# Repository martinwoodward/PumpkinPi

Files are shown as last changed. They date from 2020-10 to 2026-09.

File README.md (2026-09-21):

# PumpkinPi
Spooky build status indicator.

## Plasma 2350 W version

The new [Plasma 2350 W models](stl/plasma-2350-w/) include a board holder, a
pumpkin body with a smoothed Octocat and a USB-C panel-mount fit coupon,
with before/after previews.
See the [Plasma runtime guide](docs/plasma-runtime.md) for the offline-tested
96-LED MicroPython firmware and standalone GitHub HTTPS with a board-local token.
See the [implementation plan](docs/plasma-copilot-plan.md) for its accounting and safety
contract. Live billing and physical hardware gates remain intentionally unclaimed;
the Raspberry Pi setup below remains the unchanged legacy application.

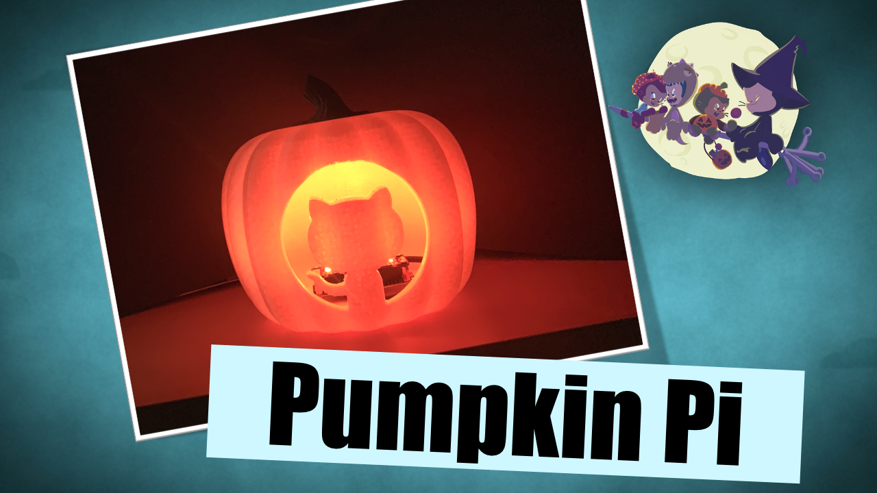
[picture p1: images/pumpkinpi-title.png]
Pumpkin Pi


## Hardware Requirements:
This project makes use of the following:
 - Pumpkin - Carve a real one or you can always [3D print one](#3d-printed-pumpkin)
 - Raspberry Pi Zero WH  ([UK](https://amzn.to/33rmXEc), [US](https://amzn.to/3lcQLul))
 - Pimoroni Unicorn pHat  ([UK](https://amzn.to/3l8rPnR), [US](https://amzn.to/30wEWaG)). Note discountinued now so you might want to try the [Unicorn HAT Mini instead](https://shop.pimoroni.com/products/unicorn-hat-mini)
 - Micro SD Card  ([UK](https://amzn.to/2SoRagP), [US](https://amzn.to/2GeMWWT))
 - USB power - I used the official Raspberry Pi Charger ([UK](https://amzn.to/33qvreN), [US](https://amzn.to/36yKkh4)) but you can also power with a USB battery pack.

 ### 3d Printed Pumpkin
 For the [3d printed pumpkin case](stl/), you will need:
  - Glow in the Dark PLA Filament for body  ([UK](https://amzn.to/2SmQzwj), [US]())
  - Green PLA Filament for top  ([UK](https://amzn.to/2GeMlo7), [US](https://amzn.to/30vuAHX))
  - Adafruit Panel Mount Extension USB Cable - Micro B Male to Micro B Female [ADA3258] ([UK](https://amzn.to/3irYgf9), [US](https://amzn.to/34pR51V))
  - 4 x M2.5 threaded brass inserts ([UK](https://amzn.to/3ixudCK), [US](https://amzn.to/33rnYw0))
  - 4 x M2.5 male PCB standoffs & screws - keep a kit of these handy if you don't have some. ([UK](https://amzn.to/3cYGkYE), [US](https://amzn.to/3l8VDk8))

When ordering online, while Amazon ([US](https://amzn.to/2CUGild)) and Amazon ([UK](https://amzn.to/2PbHDtz)) are always handy places (especially if you are a Prime member) I also highly recommend [AdaFruit](https://www.adafruit.com/) for electronics purchases in the US and [PiHut](https://thepihut.com/) in the UK. They basically should just park a truck at my house and take all my money.

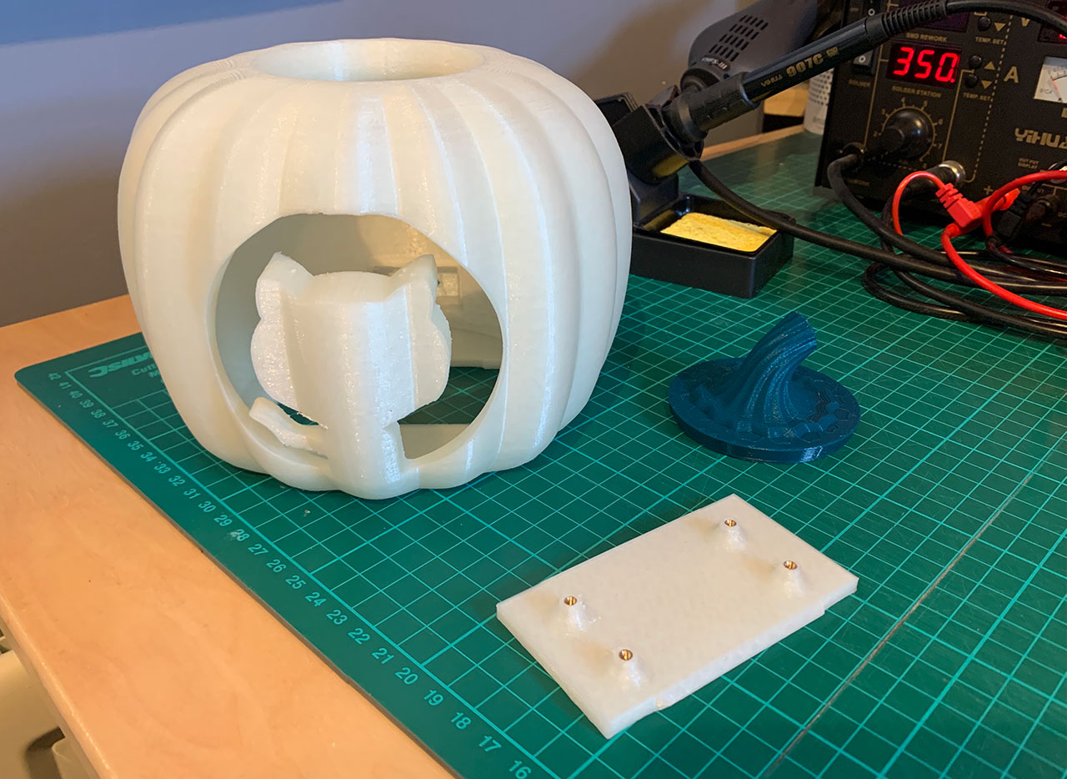
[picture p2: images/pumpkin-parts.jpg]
Pumpkin Pi


## Getting Started

Format the micro SD Card and [install Raspberry Pi OS Lite](https://www.raspberrypi.org/downloads/raspberry-pi-os/). If installing onto a Pi Zero you might not have the keyboard and HDMI adapters lying around so you probably want to do a [headless install](https://www.raspberrypi.org/documentation/configuration/wireless/headless.md), configuring SSH and WiFi by dropping an `ssh` file and a `wpa_supplicant.conf` file onto the root of the SD card after copying over the Raspbian files.

You'll need to install the [Unicorn HAT](https://github.com/pimoroni/unicorn-hat) software but they have a cool one-line installer that takes care of all the dependencies including Python and Git.

``\curl -sS https://get.pimoroni.com/unicornhat | bash``

In addition, we'll be using the ``requests`` module in python so after installing the Unicorn HAT software, install the ``requests`` module with the following command

``sudo pip install requests``

Next you want to clone this git repo. I have it at the root of the standard ``pi`` user

``git clone https://github.com/martinwoodward/PumpkinPi.git``

You need to modify the settings to point at your build badge. First of all copy the sample settings provided in the repo:

``cp ~/PumpkinPi/src/local_settings.sample ~/PumpkinPi/src/local_settings.py``

Then edit the ``BADGE_LINK`` variable and point at the URL of your Build badge.

```python
# Build Badge for the build you want to monitor
BADGE_LINK = "https://github.com/martinwoodward/calculator/workflows/CI/badge.svg?branch=main"
# How often to check (in seconds). Remember - be nice to the server. Once every 5 minutes is plenty.
REFRESH_INTERVAL = 300
```

Finally you can run the script as root

```
sudo python ~/PumpkinPi/src/pumpkinpi.py &
```

Once you are happy everything is running how you want, don't forget you can run the script at boot time. The easiest way to do this is to use crontab. See this [cool video from Estefannie over on the Raspberry Pi blog](https://www.raspberrypi.org/blog/how-to-run-a-script-at-start-up-on-a-raspberry-pi-using-crontab/) to learn more.  But basically do ``sudo crontab -e`` then add the following:

```
@reboot /bin/sleep 10 ; /usr/bin/python /home/pi/PumpkinPi/src/pumpkinpi.py &

```

Note that we are pausing for 10 seconds before running the python script. This is to allow the network to come up. We could make the python script more resilient to network outages and/or start up the script using [systemd](https://www.raspberrypi.org/documentation/linux/usage/systemd.md).

Pumpkin Pi

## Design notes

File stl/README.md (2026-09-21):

## 3D model files for Pumpkin Pi

For the **Plasma 2350 W**, see the [new model variants](plasma-2350-w/):
a replacement holder, a body with a smoothed Octocat, USB-C panel-mount revisions and preview
images. The original Pi Zero files below are retained unchanged.

There are 3 main components for the Pumpkin Pi.
 - [pumpkin-body.stl](pumpkin-body.stl) - the main body of the pumpkin. I printed without supports using glow in the dark PLA filament. Infil 15% gyroid pattern.
 - [pumpkin-pi-holder.stl](pumpkin-pi-holder.stl) - an insert that snap fits into the bottom of the pumpkin. I printed mine in the same run as the body with same settings.
 - [pumpkin-plug.stl](pumpkin-plug.stl) - the stalk part of the pumpkin that slots into the top. I printed mine in dark green PLA filament.

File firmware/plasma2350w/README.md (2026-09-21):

# Plasma 2350 W firmware

This MicroPython application drives a 96-pixel AI-credit candle using
**standalone GitHub HTTPS**. It
stores Wi-Fi credentials and the GitHub token on the Plasma 2350 W itself; no
computer or Copilot process needs to remain running.

## Standalone setup

1. Install the Pimoroni **Plasma 2350 W v1.1.0** UF2.
2. Create local private files from the committed templates:

   ```bash
   cp firmware/plasma2350w/config.github.example.json firmware/plasma2350w/config.json
   cp firmware/plasma2350w/.env.example firmware/plasma2350w/.env
   chmod 600 firmware/plasma2350w/.env firmware/plasma2350w/config.json
   ```

3. Edit `.env` **locally, not in chat or a shell argument**. Set `WIFI_SSID`,
   `WIFI_PASSWORD`, and `GITHUB_TOKEN`. This is a literal file, not a shell script:
   optional matching quotes are removed, but escapes, interpolation, `export`,
   and inline comments are not supported. A password can contain `#` or `=`.
   Blank values, duplicate/unknown keys and control characters are rejected.
4. Edit `config.json`: supply the actual payer/account, an approved
   `allowance_microcredits` (one credit = 1,000,000 microcredits), and verified
   `unit_type`, `product`, `sku`, and `quantity_field` from that account's billing
   response. For an organization or enterprise set `owner_type`, `owner` and,
   if appropriate, `source.subject`. See [accounting requirements](../../docs/plasma-runtime.md#live-source-provisioning).
   Empty template fields intentionally prevent live startup and select a
   clearly marked setup demo; there is no guessed quota or demo data in live mode.
5. The template selects `exhaustion_policy: "configured-budget"`: zero triggers
   the exhausted animation for **your named monthly budget**, not necessarily
   your GitHub account. Use `"none"`
   for an estimated allowance that must not claim exhaustion. Change
   `budget_revision` when you change the budget.
6. Reboot normally into MicroPython, connect the serial USB port, then upload:

   ```bash
   python3 -m venv .venv
   .venv/bin/python -m pip install -r firmware/plasma2350w/requirements.txt
   .venv/bin/python firmware/plasma2350w/deploy.py install \
     --device /dev/cu.usbmodemXXXX \
     --mpremote .venv/bin/mpremote \
     --config firmware/plasma2350w/config.json \
     --env firmware/plasma2350w/.env
   .venv/bin/mpremote connect /dev/cu.usbmodemXXXX reset
   ```

The actual `.env` and `config.json` are ignored by Git; `.env.example` is tracked.
Only explicit `--env` uploads secrets, to the board's `/.env`. The token never
appears in command arguments, normalized snapshots, status or network errors.
Board flash is **not encrypted secret storage**: anyone with physical access can
read it. Use a minimally privileged, revocable token. To rotate it, update the
private `.env`, upload that file with `mpremote ... fs cp path/to/.env :.env`,
reset the board and revoke the old credential. Do not commit flash dumps or
private backup files.

### Network, time and trust

The board cooperatively performs DHCP-resolver IPv4 DNS, NTP bootstrap, and
GitHub HTTPS. The actual RTC is set before TLS starts (including 2000-epoch
MicroPython ports). NTP is **unauthenticated clock bootstrap**, not server
authentication. Every request requires a trusted CA and the hostname
`api.github.com`; no redirect is followed and no `CERT_NONE` fallback exists.
See [the bundled CA's provenance and rotation](certs/README.md).

GitHub's verified HTTP Date must agree within five minutes. A saved
`direct-time.json` lower bound rejects substantial rollback across boots; it is
updated at most once daily after a verified response. A corrupt or unreadable
file is an explicit startup error: inspect the device rather than silently
discarding rollback protection. Time resynchronizes every six hours and after
TLS/time disagreement; the filesystem and RTC must be functional.

Allow outbound DNS (UDP 53), NTP (UDP 123), and HTTPS (TCP 443). `ntp_host` can
name a local NTP server if public NTP is blocked. DNS and NTP have five-second
deadlines; a full HTTPS operation has fifteen seconds, 8 KiB of headers and a
32 KiB body maximum. Billing normalization is limited to 512 rows with exact
decimal arithmetic, not float-rounded credit quantities. Oversized or unsupported
responses fail visibly rather than truncating usage or displaying a guessed balance.

Polling defaults to five minutes and honors rate-limit delays with bounded-work
exponential retries. GitHub's reporting latency is unknown, so effects represent
**newly reported** consumption, not every keystroke. DNS/TLS/HTTP progress is
cooperative with the 30 fps scheduler; no `urequests.get()` blocks the render loop.
Failures preserve the prior observation without renewing freshness or inventing
zero. The onboard status LED signals errors/staleness. A serial REPL traceback
identifies startup configuration errors. Actual UF2 frame timing still needs
measurement; cryptographic work and JSON parsing are not preemptible.

## Candle behaviour and button A demo

Full credits show a **golden flickering candle with recurring white sparkles**.
The palette passes through orange/red and purple as the balance falls; sparkles
stop below 100%. At confirmed zero the two-second sputter now settles into a
**dull purple flicker**, not complete darkness. Repeated zero reports do not
restart it. When credits return, the light rises to bright white over **one
second**, then blends into the credit-dependent candle over half a second.
At full balance this is golden with white sparkles again. An unconfirmed
estimated zero keeps the existing brighter low-balance purple instead.

An unlimited basis must be explicitly approved: set `source.unlimited: true` and
`source.allowance_microcredits: null` in the board config. Unlimited
snapshots still require a successful, mapped usage report; missing data, null
allowance alone, paid overages and authentication errors never imply unlimited
credits. Sparkles continue while the configured unlimited basis is active.

Press **A** (active-low `SW_A` / GPIO12 on the Plasma 2350 W, with a pull-up and
50 ms debounce) to enter animation demo mode. The sequence is:

| Stage | Duration |
| --- | --- |
| Three white flashes | 250 ms on, 250 ms off each (1.5 s total) |
| Dark pause | 15 s |
| Full golden candle with white sparkles | 10 s |
| Smooth simulated consumption from 100% to zero | 30 s |
| Exhausted state | 5 s, including the initial 2 s sputter then dull flicker |
| Recharge to white | 1 s, then 0.5 s blend into golden |
| Repeat the complete sequence, including flashes and pause | Three cycles total (63 s each) |
| Full orange/golden flickering candle with recurring white sparkles | 60 minutes |
| Replay the complete sequence once, then return to the 60-minute candle | Repeats until reset/power-off |

The initial three cycles take 189 seconds. The first hourly replay begins at
3,789 seconds after demo entry and finishes at 3,852 seconds. Each subsequent
hold lasts a full 3,600 seconds, followed by one 63-second sequence. Timing uses
monotonic elapsed time, not wall-clock synchronization or frame count; delayed
frames do not accumulate timing drift. Each new cycle clears prior animation
effects without resetting or populating live accounting.

Demo is latched in memory: more button presses and later network availability do
not restart or cancel it. Polling stops and active sockets close; synthetic demo
values never enter live accounting or persistent billing state. The onboard
status LED is **blue** and the serial console gives a secret-free entry reason.

Every fully provisioned boot starts in **normal mode**. If no fresh, valid balance arrives within
**30 seconds**, it enters the same demo automatically. Set
`startup_demo_timeout_seconds` (greater than 0, at most 300) to allow a slower
network. Wi-Fi, DNS, TLS, authorization or unsupported-response failures can all
prevent a usable startup reading; the recorded error remains available for
diagnostics. A later outage after a successful startup stays in normal mode with
the existing stale/error indication, rather than switching to synthetic full
credits. Reset/power-cycle to retry live mode after fallback.

Missing, unreadable or invalid `config.json` / `.env` instead reports a
secret-free **Setup required** error and immediately enters the same latched
demo with blue status. No network provider is created and live accounting stays
unknown. The error remains in the reducer for diagnostics. An invalid config
uses the default RGB order, 96 pixels, 100% requested brightness and modeled 1.5 A cap; an invalid
environment with a valid config preserves that config's electrical settings.
Hardware/code failures and corrupt TLS time-floor state still fail explicitly,
not as setup demos. Complete the settings and reset to retry live mode.
All frames, including flashes,
recharge white and sparkles, obey the same brightness/current caps; "bright"
never means bypassing the configured electrical limit.

## Deployment details

The RP2350 BOOTSEL drive is a UF2 bootloader volume, **not** the MicroPython user
filesystem: do not copy `.py` files to it. The `install` command uses `mpremote`
to create package directories and upload `main.py`, the scheduler, hardware
adapter, GitHub provider, cooperative networking, the CA certificate, every
`pumpkinpi_core/` module, and only explicitly supplied private files.

For inspection or packaging without a device:

```bash
python3 firmware/plasma2350w/deploy.py bundle build/plasma-firmware
```

The bundle command accesses only the named local folder and never uploads secrets.
The deployment requirement is only `mpremote`; no desktop runtime is installed.

### Windows serial REPL and first deployment

The attached board was identified on **COM5** as `plasma_2350_w`, MicroPython
1.27.0 (2026-03-02), `Pimoroni Plasma 2350 (LTE + WiFi) with RP2350`.
Discover the current port rather than assuming COM5 on another machine:

```powershell
Get-CimInstance Win32_SerialPort | Select-Object DeviceID,Name,PNPDeviceID
python -m venv .venv
.\.venv\Scripts\python.exe -m pip install -r firmware\plasma2350w\requirements.txt
.\.venv\Scripts\mpremote.exe connect COM5 exec "import os, sys; print(os.uname()); print(sys.implementation); print(os.listdir())"
```

`mpremote` uses MicroPython's raw serial REPL. `exec`, `run` and `fs` normally
interrupt the application and soft-reset the interpreter; they are not passive
monitoring. Use one serial client at a time, close editors/serial monitors first,
and always reset after inspection to leave `main.py` running autonomously.
Preserve an existing boot program on the board before the first overwrite; do
not read or dump existing credentials. This board's prior boot program is
preserved as `main-before-pumpkinpi.py` (the pre-existing `main-original.py` and
`secrets.py` were left untouched).

For an **explicitly approved unprovisioned setup**, upload the blank templates:

```powershell
.\.venv\Scripts\python.exe firmware\plasma2350w\deploy.py install --device COM5 --mpremote .\.venv\Scripts\mpremote.exe --config firmware\plasma2350w\config.github.example.json --env firmware\plasma2350w\.env.example
.\.venv\Scripts\mpremote.exe connect COM5 run firmware\plasma2350w\verify_demo.py
.\.venv\Scripts\mpremote.exe connect COM5 reset
```

The board gets `/config.json` with empty account/mapping fields and a `_setup`
array of instructions (JSON does not allow comments), plus `/.env` with comments
and blank credentials. **Do not overwrite provisioned private files with these
templates.** For code-only updates omit both `--config` and `--env`. To provision
live mode later, edit ignored local copies and explicitly upload those files;
do not paste secrets into REPL commands or chat.

`verify_demo.py` executes from the host through the REPL without installing a
test program on the board. It exercises real hardware for roughly 191 seconds
(plus up to the configured startup timeout), checks all three initial cycles
and the orange hold, nonzero
output in each lit phase, the dark pause, power/brightness limits, and absence
of synthetic billing snapshots. It is for an unprovisioned/offline board, not
one currently showing a valid live balance. It blacks the strip on exit, so
**reset afterward**. Its checks add rendering overhead; do not interpret its
frame count as an uninstrumented frame-rate benchmark. It then advances the
demo timestamps through two hourly replays to check exact 60-minute boundaries
and real hardware writes without waiting two hours; this is not a real-time
two-hour soak. Serial verification
cannot establish perceived colors, measured electrical current or temperature.
On the attached board a separate, uninstrumented golden-candle sample rendered
128 frames in 10.06 seconds (about 12.7 fps), below the 30 fps scheduler target.

Start with 96 WS2812 pixels in **RGB order**, matching this board's `fire.py`
and `rainbows.py` examples. GRB swapped red/green and made the golden candle
look green on the attached strip. Set `color_order` explicitly for other strips;
do not compensate by changing the logical candle palette. The strip is black before
`strip.start(60)`. The default requests 100% brightness, matching the existing
board examples (`rainbows.py` uses HSV value 1.0; `fire.py` reaches toward 1.0;
`sparkles.py` reaches RGB values near 254). Those examples address 50 pixels,
not this application's 96, and do not establish safe full-strip white current.
The provisional **1.5 A total modeled-current cap remains active**, scaling
bright frames down as needed. Existing explicit brightness settings are
preserved on code-only updates; edit `max_brightness` to `1.0` to opt in.
These brightness and current settings are not
electrical certification; identify the LEDs and verify current with a meter.
Fatal errors and normal interpreter shutdown execute a final blackout, but physical
power-loss behavior must still be checked on the actual DMA/strip firmware.
The onboard status LED uses Pimoroni's documented
`RGBLED("LED_R", "LED_G", "LED_B")` pin-name API.

## Hardware gates

Board entropy, DNS/NTP/HTTPS timing, onboard RGB LED pin names,
actual colour order, current, temperature, and an eight-hour soak remain physical
tests. The HTTPS implementation has host tests including real local TLS success,
wrong CA/hostname and expired-certificate rejection without transmitting an
application credential. Public DNS, NTP and GitHub TLS with the bundled root
were also exercised from the host, using a synthetic invalid credential (401).
The serial deployment and full setup-demo sequence have now been exercised on
the attached physical board with blank credentials. No actual billing token was
supplied: live entitlement/unit mapping, RP2350 networking/heap behavior under
load, physical color/current/temperature checks and soak testing remain gates,
not claims inferred from the setup demo.

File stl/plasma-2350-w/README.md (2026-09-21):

# Plasma 2350 W PumpkinPi models

These are new variants; the original Pi Zero STLs remain unchanged in the parent
directory. All dimensions are **millimetres**. New files are **Z-up, base on Z=0**,
ready for normal upright printing. Do not auto-rotate them onto their sides.

| File | Purpose |
| --- | --- |
| [plasma2350-holder.stl](plasma2350-holder.stl) | Plasma 2350 W insert, retaining the original snap-fit perimeter |
| [pumpkin-body.stl](pumpkin-body.stl) | Original shell with an evenly thinned Octocat and revised USB-C panel opening |
| [usb-c-fit-coupon.stl](usb-c-fit-coupon.stl) | Small, flat-printed connector-pattern trial; print this first |
| [measurements.json](measurements.json) | Regenerated mesh measurements and geometry checks |

Use the existing [pumpkin-plug.stl](../pumpkin-plug.stl) for the stalk. It is still
in the legacy Y-up orientation: rotate it -90 degrees about X and place its bottom
on the bed when printing separately.

## Holder

The board is **Plasma 2350 W**, not a Pi Zero or the non-wireless Plasma 2040.
Pimoroni specifies a 60 x 22 mm PCB and an approximately 61 x 22 x 12 mm assembled
envelope including connectors. The new insert has two diagonal mounting bosses,
not the Pi Zero's four.

The [W-specific pinout drawing][pinout-w] and the [originally supplied pinout][pinout]
show two M2 mounting holes. The inferred centre separation is **55.6 x 17.6 mm**:
the vector drawing places their centres 2.2 mm in from each PCB edge. This pitch is
measured from the scaled drawing, not explicitly dimensioned by its author.
Check it against the physical board before tightening screws.

- Boss tops are at Z=11: **6 mm clearance above the plate** for underside components.
- Two **2.4 mm through-bores**, with **4.3 mm across-flats, 2 mm deep M2 nut pockets**
  entered from below. The pockets taper into the bores to avoid horizontal roofs.
- Use two M2 nuts and approximately **M2 x 12 mm screws**, adjusting length for
  actual PCB thickness and washers. Use insulating washers and do not overtighten.
  Do not substitute the old M2.5 inserts.
- Retained plate envelope: **89 x 54 mm**, with the original 5 mm thick snap profile.
  Screws/nut pockets only alter its interior, not the mating rim.
- Both board ends are open for the USB-C plug and LED terminal wiring. The preview
  ghost is a PCB envelope, not a component-accurate clearance model.
- Install the board and cable on the holder before snapping it into the pumpkin;
  keep the 30 cm cable loosely routed around the interior, away from LED wiring
  and the wireless module. Check the actual 37 mm plug/strain-relief envelope and
  cable bend radius during dry assembly.

## Body and support constraints

The body retains the original shell and crown, with a locally smoothed Octocat
and the USB-C revision described below.
The first 6 mm of the body and the stalk seat from Z=112 upward are unchanged.

### Smooth Octocat back

The Octocat has a **3.2 mm front-to-back wall** instead
of letting the general cavity leave ridges and a thick wedge behind its head.
The back follows a smooth offset of the existing sculpted front, preserving the
visible silhouette and outer surface. The lower front wall continues the relief
into the original base, without a new unsupported ledge. The surrounding crown
still retains its support-free roof; only the logo is uniformly thinned.

This dimension is measured along Y (front to back), not perpendicular to every
facet of the curved exterior. The generator checks 2,266 points across the head,
stem and tail; the exported surfaces measure **3.17-3.26 mm**, excluding rays
grazing the original cutout bevels. It also checks the front surface is unchanged
and introduces no new steep underside faces. The smooth offset is reconstructed
from the source exterior, not from the jagged old inner wall.

### Printing

The generator checks the actual exported meshes are single watertight solids,
checks both old/new holders against the body, and rejects newly introduced downward
faces above 45 degrees **except the flat USB ceiling**. This is an explicitly
accepted **11.6 mm bridge for the Bambu X1C**; the exception is constrained to that
ceiling, not the rest of the shell. The source pumpkin already contains steep
faces/bridges, so not every pre-existing face is below that angle. Inspect the sliced
layers, particularly the face and rear connector, with bridging enabled.

Starting point: PLA, 0.4 mm nozzle, 0.2 mm layers, 3-4 perimeters, 10-15% infill,
supports off, brim only if needed for bed adhesion. Use the same settings when
comparing slicer filament estimates. Glow PLA is abrasive; use a
suitable nozzle. No physical test print or thermal test has been performed.

## USB-C panel mount: provisional fit, coupon first

The supplied [BTFO USB-C panel extension][cable] drawing gives:
30 cm cable, 25 x 10 mm flange, approximately 35 mm female housing length,
37 mm male housing length and 9 mm screws. **It does not specify screw-centre
spacing, screw diameter, through-panel cutout or rear housing cross-section.**
Do not infer a guaranteed fit from the illustration.

The old micro-B opening was 10 x 5 mm with bores on a 16.5 mm pitch. The Plasma body
uses:

- An **11.6 x 6.8 mm rectangular opening** with a flat, bridged ceiling.
- Nominal **19 mm screw pitch** with 4.8 mm diagonal diamond bores. Their inscribed
  circular diameter is about 3.39 mm; these are clearance holes, not printed threads.
- The same recessed rear position and 2 mm mounting face.
- No triangular vent above the opening. The 6.8 mm height fits within the pictured
  centred 10 mm-high flange, without the previous 4.2 mm protruding tip. This is
  still not a sealed or weatherproof connector mount.

Print `usb-c-fit-coupon.stl` (34 x 19 x 2 mm) first, use the supplied cable to verify
the aperture and screws, and measure the flange and inner moulding against the
recess. **The coupon checks the face pattern, not rear housing or cable clearance.**
Check the supplied 9 mm screw engagement in the actual connector; add washers or
use shorter screws if they bottom out. Never force the plastic or connector.

If needed, update `MOUNT_X` (half the screw pitch), `PORT_WIDTH`, and `PORT_HEIGHT`
in the generator, then regenerate **both the coupon and body**. Verify that
there is still material between holes and that the flange covers the intended
opening. A measured connector cutout drawing is required to finalize this fit.

## Rebuild and previews

From the repository root:

```sh
python3 -m venv .venv
.venv/bin/python -m pip install -r stl/tools/requirements.txt
.venv/bin/python stl/tools/build_plasma.py
```

The generator uses the original binary STLs as source, not an approximate
replacement pumpkin. It preserves their licence and produces new binary STLs,
measurement JSON and the previews below. No CAD application is required.

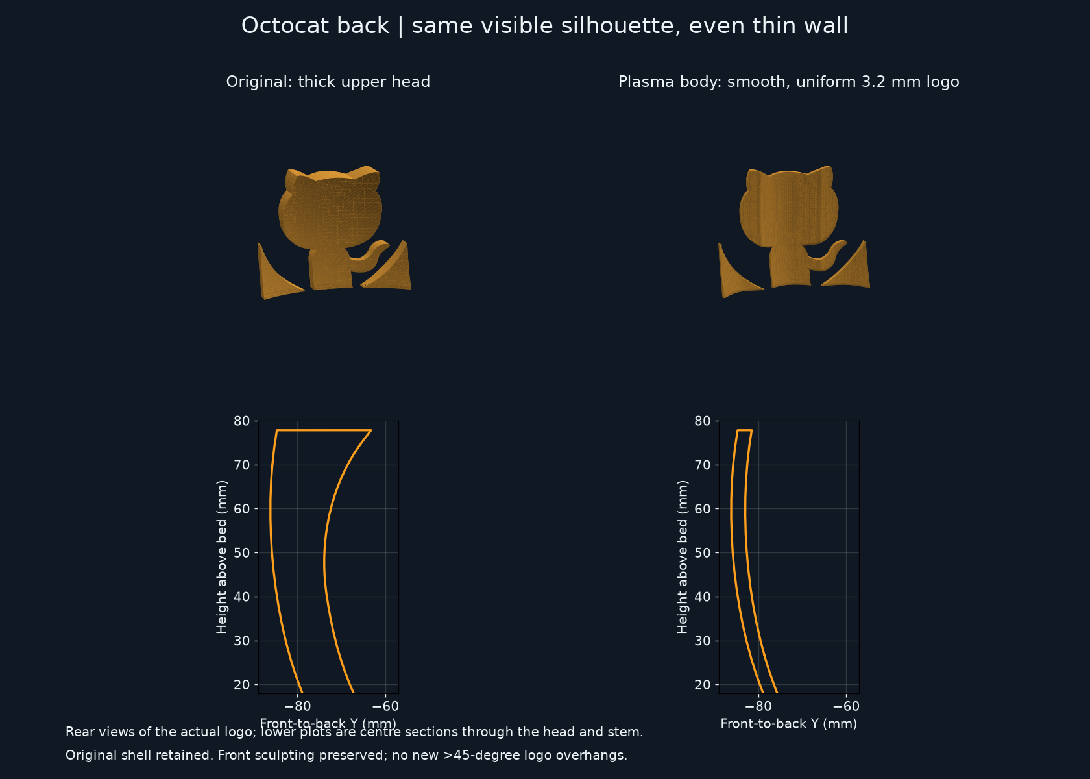
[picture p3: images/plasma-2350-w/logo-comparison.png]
Octocat back before and after, with wall-depth sections


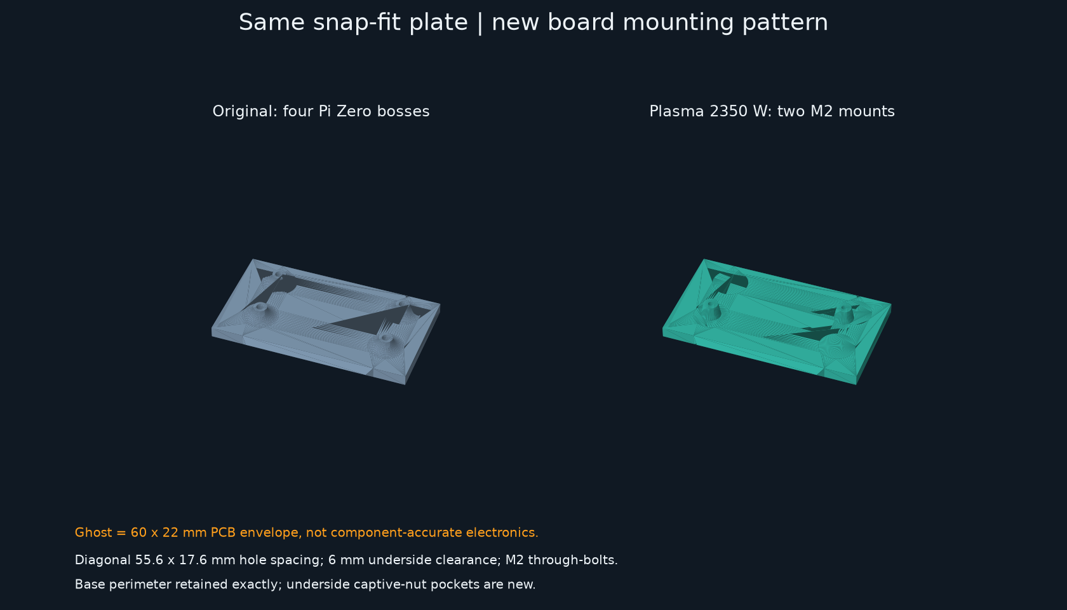
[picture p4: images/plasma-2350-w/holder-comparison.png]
Original and Plasma mounting plates


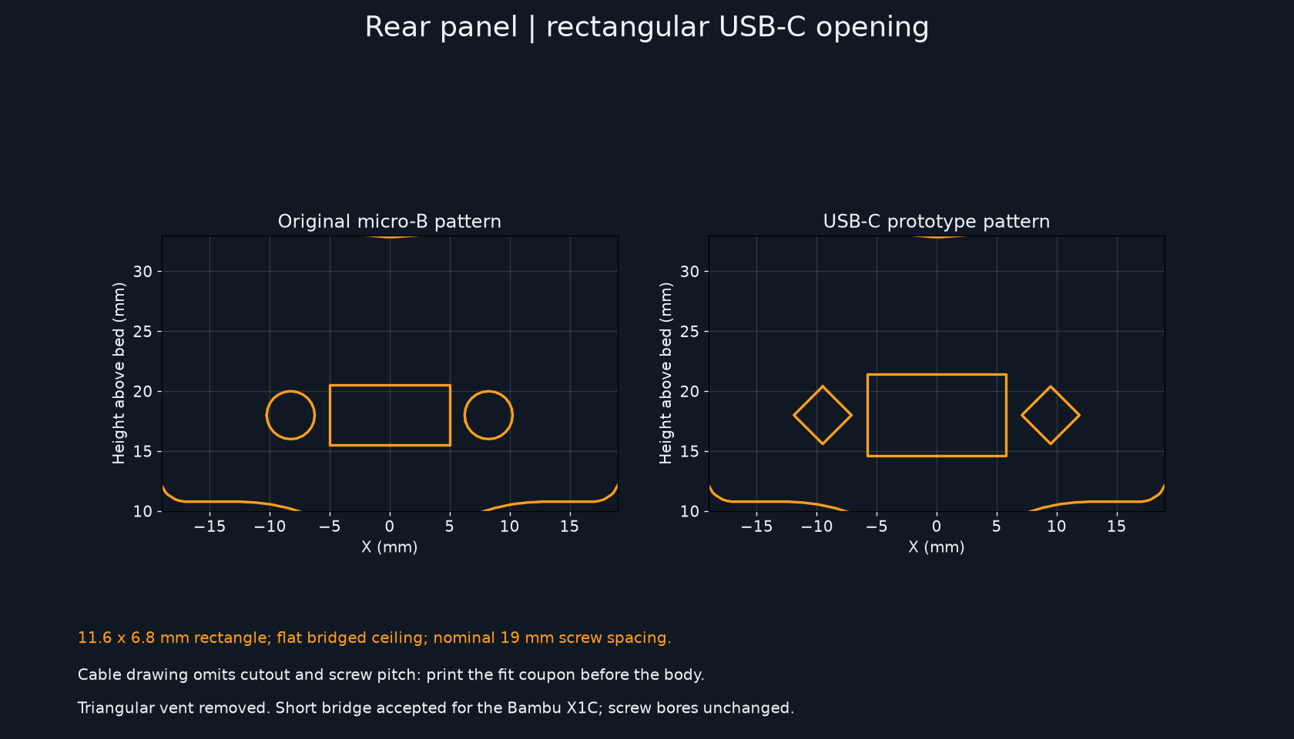
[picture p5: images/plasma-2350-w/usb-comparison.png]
Original and USB-C panel patterns


See the [preview gallery](../../images/plasma-2350-w/index.html) and
[Copilot credit-lamp implementation plan](../../docs/plasma-copilot-plan.md).

[pinout]: https://cdn.shopify.com/s/files/1/0174/1800/files/plasma2350_pinout_diagram.pdf?v=1723124465
[pinout-w]: https://cdn.shopify.com/s/files/1/0174/1800/files/plasma2350_w_pinout_diagram.pdf
[cable]: https://www.amazon.co.uk/dp/B0H7S5WSC5

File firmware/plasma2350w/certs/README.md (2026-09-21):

# GitHub HTTPS trust anchor

`github-root.pem` contains the public **USERTrust ECC Certification Authority**
root, extracted from the development host's trusted CA store on 18 September
2026. It contains no private key or account credential.

- DER SHA-256: `4ff460d54b9c86dabfbcfc5712e0400d2bed3fbc4d4fbdaa86e06adcd2a9ad7a`
- Expiry: 18 January 2038.
- Observed `api.github.com` chain: `*.github.com` ->
  `Sectigo Public Server Authentication CA DV E36` ->
  `Sectigo Public Server Authentication Root E46` ->
  `USERTrust ECC Certification Authority`.

The shipped cooperative HTTPS transport validated GitHub's current chain using
this bundle during a credential-free connectivity check (a synthetic invalid
bearer value received the expected HTTP 401). Local TLS tests also reject
untrusted roots, hostname mismatch and expired certificates before application
headers are transmitted.

This is a deliberately small **root trust bundle**, not a pinned GitHub leaf
certificate or a promise that GitHub will retain this issuer. Normal leaf
renewals under the same chain need no update. If GitHub changes its chain,
obtain the required root from a trusted CA distribution, independently verify
its subject/fingerprint and validity, update this file and its fingerprint test,
and redeploy it. A MicroPython `cafile` can contain multiple PEM roots if needed
for a verified transition. Do not trust a certificate solely because a failed
connection presented it, pin a short-lived leaf to work around missing roots,
or disable `CERT_REQUIRED`/hostname checks.

The actual board RTC must be set before certificate validity checks. NTP is
unauthenticated bootstrap; the firmware additionally compares verified HTTP Date
and persists a daily lower time bound. Physical access can modify both flash and
the stored credential, so this does not provide tamper-resistant storage.

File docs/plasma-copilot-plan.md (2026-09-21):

# Plasma PumpkinPi: standalone credit candle design

Target: **Plasma 2350 W, 96 RGB LEDs**. The existing Raspberry Pi application in
`src/` remains separate and unchanged. The firmware implementation and desktop
tests are complete; actual-account authorization and physical-board acceptance
remain unverified. See the [runtime guide](plasma-runtime.md) for provisioning.

## Architecture

```text
GitHub billing REST
  -> cooperative DNS / NTP / verified HTTPS
  -> exact credit normalization
  -> ordered accounting snapshots
  -> candle / consumption pulse / recharge
  -> final brightness and current limiter
  -> 96-pixel Plasma output

Button A or startup timeout -> latched animation demo -> same effects and limiter
```

No LLM runs on the microcontroller. No paid model call is needed to update the
lamp. The optional setup skill assists provisioning; the board performs all
ongoing polling itself.

| Implementation | Responsibility |
| --- | --- |
| `firmware/plasma2350w/main.py` | Configuration, Wi-Fi adapter, actual RTC setup and shutdown blackout |
| `environment.py` and `.env.example` | Literal private credential loading and secret-free template |
| `providers/direct_network.py` | Bounded, cooperative DNS, NTP and certificate-verified HTTPS |
| `providers/github.py` | UTC monthly polling, retries, date checks and normalized snapshots |
| `pumpkinpi_core/billing.py` | Exact decimal normalization with explicit unit mapping |
| `pumpkinpi_core/accounting.py` | Sequence, scope, period, correction and freshness validation |
| `pumpkinpi_core/candle.py` and `runtime.py` | Candle, consumption pulse, depletion and recharge |
| `pumpkinpi_core/demo.py` | Monotonic, synthetic display sequence isolated from billing |
| `scheduler.py` and `hardware.py` | 30 fps updates, debounced button A and status LED |
| `pumpkinpi_core/power.py` | Final electrical model and brightness cap |
| `deploy.py` and `requirements.txt` | Local bundle export and explicit serial upload using mpremote |

## Accounting and authorization

Use the documented AI-credit usage routes:

```text
GET /users/{username}/settings/billing/ai_credit/usage?year=YYYY&month=M
GET /organizations/{org}/settings/billing/ai_credit/usage?year=YYYY&month=M&user=USERNAME
GET /enterprises/{enterprise}/settings/billing/ai_credit/usage?year=YYYY&month=M&user=USERNAME
```

Omit the subject filter for a whole organizational pool. The API version is
`2026-03-10`. Verify the actual payer and access policy: personal usage does not
include employer-funded consumption. Do not invent token scopes or automatically
request broad privileges.

The response reports usage, not a universal remaining wallet. Provision a named
monthly allowance/budget and an approved exact `unitType`, product, SKU and
quantity field. Do not subtract billed money, token counts or premium requests
from a credit allowance. Sum exact decimal quantities before converting to
integer microcredits; reject unsupported precision instead of rounding away a
positive balance.

Snapshots carry opaque profile/budget identities, generation, stream/sequence,
UTC billing period, observation time, quality, used/limit/remaining microcredits,
explicit unlimited status and configured-budget exhaustion. Unknown data is
distinct from zero. An unlimited snapshot requires local authorization, known
usage, null limit/remaining, and cannot claim exhaustion.

First observations, corrections, reconnects and new periods establish baselines
without inventing consumption. Only positive cumulative deltas within the same
basis queue bounded activity effects. A response must match the immutable month
requested; crossing a month boundary forces a new request. Failed polls do not
refresh age. UTC rollback, large jumps and old periods invalidate current claims.

## Trust and resource limits

Credentials are in ignored board-local `.env`, uploaded only via explicit
`--env`. Flash is physically readable: use revocable credentials and never commit
private config, tokens or flash dumps.

TLS requires the bundled trusted root, `CERT_REQUIRED`, and hostname verification
for `api.github.com`. Never follow redirects or disable verification. NTP is
unauthenticated RTC bootstrap, not GitHub authentication. Check verified HTTP
Date against the board clock and preserve a daily verified lower time bound.
See the [CA provenance and rotation guide](../firmware/plasma2350w/certs/README.md).

DNS/NTP deadlines are five seconds and HTTPS is fifteen seconds. Bound headers
to 8 KiB, bodies to 32 KiB and billing rows to 512. Exceeding a limit is an explicit
error, not permission to truncate usage. Poll every 300 seconds by default and
honor rate-limit delays with backoff. Reporting latency is unspecified.

## Animation and controls

| State | Effect before electrical limiting |
| --- | --- |
| Full / explicitly unlimited | Golden `(255, 170, 45)` flicker and recurring white sparkles |
| 50% | Orange-red `(255, 132, 72)` |
| 20% | Red `(235, 40, 25)` |
| 10% | Red-purple `(180, 20, 100)` |
| Low positive / unconfirmed estimated zero | Purple `(100, 12, 170)` |
| Confirmed configured-budget zero | Two-second sputter, then persistent dull purple flicker |
| Recovery | One-second rise to white, then half-second blend to the current-balance candle |

Repeated zero reports do not restart the sputter. Activity pulses cannot override
depletion. Preserve pending recharge across an unknown-period gap, without
pretending the previous month is current.

Button A is active-low `SW_A` / GPIO12 with a pull-up and 50 ms debounce. Demo
flashes three times (250 ms on/off), waits 15 s, stays full 10 s, drains over 30 s,
stays exhausted 5 s including sputter, and recharges over 1.5 s. Run three full
63-second cycles, hold the orange/golden candle for 60 minutes, then repeatedly
run one complete cycle followed by another 60-minute hold until restart.
The blue status LED marks simulation. Polling stops; synthetic values do not
enter the accounting reducer or saved billing state.

Every fully provisioned boot begins in normal mode. After 30 s without fresh valid credit data,
enter the same latched demo. Make the startup timeout configurable. A later
outage after a successful startup retains live-mode error/stale handling.
Missing or invalid local configuration/environment reports a secret-free setup
error and immediately starts the blue-status demo without network access or
synthetic billing state. Hardware and TLS time-floor failures remain fatal.

## Power and physical acceptance

Default to 96 WS2812 RGB pixels, RGB order, 100% requested brightness and a provisional
1.5 A modeled LED budget. An older 96-pixel strip can demand about 5.76 A at
full white, beyond the board's published 3 A USB-C limit. All effects, including
flashes and recharge, pass through the same limiter. An impossible visibility
budget raises a diagnostic instead of bypassing the cap.

Before declaring hardware-ready, verify board/button APIs on the actual UF2,
LED order, current at worst-case white, cable/connector ratings, temperature,
Wi-Fi recovery, TLS memory and frame timing, clock/reset behaviour and an
eight-hour soak. `strip.start(60)` repeats DMA output; the scheduler must still
generate animation frames. The power limiter is not short-circuit protection.

## References

- [GitHub billing REST usage](https://docs.github.com/en/rest/billing/usage)
- [MicroPython TLS verification](https://docs.micropython.org/en/latest/library/ssl.html)
- [Plasma 2350 W hardware](https://shop.pimoroni.com/products/plasma-2350-w)
- [Pimoroni Plasma v1.1.0](https://github.com/pimoroni/plasma/releases/tag/v1.1.0)
- [Pinned Plasma driver API](https://github.com/pimoroni/plasma/blob/6440caf5f6a04834bcd489932bbcf7015d3626d7/docs/plasma.md)
- [Pinned board pins](https://github.com/pimoroni/plasma/blob/6440caf5f6a04834bcd489932bbcf7015d3626d7/boards/plasma_2350_w/pins.csv)
- [Printable models and physical-fit caveats](../stl/plasma-2350-w/README.md)

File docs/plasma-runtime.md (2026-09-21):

# PumpkinPi Plasma runtime

The Plasma 2350 W connects directly to GitHub over verified HTTPS and drives
exactly 96 RGB LEDs. The token and Wi-Fi credentials live on the board. No
computer, background service or model call is needed during operation.

## Setup and upload

Follow the [firmware setup guide](../firmware/plasma2350w/README.md#standalone-setup):
copy `config.github.example.json` to ignored `config.json`, copy `.env.example`
to ignored `.env`, then fill in the private credentials and approved billing
configuration. Install the serial upload tool from
`firmware/plasma2350w/requirements.txt` and run:

```bash
.venv/bin/python firmware/plasma2350w/deploy.py install \
  --device /dev/cu.usbmodemXXXX --mpremote .venv/bin/mpremote \
  --config firmware/plasma2350w/config.json \
  --env firmware/plasma2350w/.env
.venv/bin/mpremote connect /dev/cu.usbmodemXXXX reset
```

Only explicitly supplied `--env` uploads secrets. Board flash is physically
readable, not encrypted secret storage: use a minimally privileged, revocable
token and never commit credentials or flash dumps. The BOOTSEL USB volume
accepts UF2 firmware, not Python filesystem files.

## Live source provisioning

Configure these fields in the board `config.json`:

- `source.owner_type`: `user`, `organization`, or `enterprise`, with the exact
  `source.owner` and optional organization/enterprise `source.subject`.
- `source.allowance_microcredits`: an approved named monthly allowance or budget;
  one credit equals 1,000,000 microcredits. Manually configured allowances are
  `estimated`, not evidence of GitHub account lockout.
- `source.mapping`: exact `unit_type`, `product`, `sku`, and `quantity_field`
  (`grossQuantity`, `discountQuantity`, or `netQuantity`) verified from an
  authorized response. Never infer credits from money fields, token counts,
  premium-request quotas or plan names.
- `exhaustion_policy`: `"configured-budget"` only when zero for that named budget
  should trigger the exhausted animation; otherwise `"none"`.

For an explicitly approved unlimited basis, set `source.unlimited: true` and
`source.allowance_microcredits: null`. The board still fetches and validates usage.
Missing amounts, failed requests and paid overages do not imply unlimited credits.
Change `budget_revision` when changing the balance definition.

The documented AI-credit API reports usage, not a universal remaining wallet.
A personal endpoint does not report employer-funded usage. Verify the actual
payer, token access, allowance and units locally before enabling live reporting.
Do not guess token scopes or paste a token into chat.

## Candle and demo

Full credits show a golden candle with recurring white sparkles. The palette
moves through red and purple as credits fall; sparkles stop below 100% and remain
active for explicitly unlimited credits. Confirmed zero sputters for two seconds,
then stays in a dull purple flicker. Recovery rises to white over one second and
blends back into the current-balance candle over half a second.

Press button **A** to start the latched animation demo: three flashes, a 15-second
pause, 10 seconds full, 30 seconds draining, 5 seconds exhausted, then recharge.
Run this complete 63-second sequence three times, then hold the
orange/golden flickering candle for 60 minutes. Thereafter replay the sequence
once and hold orange for another 60 minutes, repeating until restart. All
durations use monotonic time; network recovery or another button press does not
restart the schedule. A blue onboard LED marks simulation. It stops
network polling and never writes synthetic values into live billing state.

Every fully provisioned boot starts in normal mode. With no fresh valid credit data after 30 seconds,
it starts the same demo automatically. `startup_demo_timeout_seconds` can be
increased for a slower network. Later outages after a successful startup retain
normal stale/error handling instead of switching to simulated full credits.
Missing, unreadable or invalid `config.json` / `.env` reports a secret-free
`Setup required` error and immediately starts blue-status setup demo without
creating a network provider or populating live accounting. Invalid config uses
default power settings (96 RGB-order pixels, 100% requested brightness, modeled 1.5 A
total cap); valid config with
invalid environment retains the validated electrical settings. Hardware/code
and TLS time-floor failures remain fatal. Fill the board's commented `.env` and
`config.json` setup fields and reset to retry live mode. See the firmware README
for Windows serial commands and the real-board `verify_demo.py` smoke test.

## Network and diagnostics

The cooperative scheduler advances DNS, NTP and verified TLS alongside animation.
Allow outbound UDP 53/123 and TCP 443. The bundled CA verifies `api.github.com`;
redirects and insecure TLS fallbacks are prohibited. NTP bootstraps the actual RTC,
including ports with a 2000 epoch. NTP itself is unauthenticated; verified HTTP
Date and a saved daily time floor provide additional checks.

Five-minute polling observes newly reported usage, not necessarily each
interaction. GitHub reporting latency is unspecified. Failed requests preserve
the prior observation without renewing its freshness or inventing zero. Reports
are bounded to 32 KiB and 512 rows and normalized using exact decimal arithmetic.
Oversized reports fail explicitly rather than truncating usage.

Inspect the status LED and secret-free serial error for Wi-Fi, authorization,
clock, certificate, mapping or response-size failures. Blue means demo, red
means error, purple means stale, and amber marks unknown/estimated data. Never
disable certificate verification to get past a connection failure.

## Optional setup skill

`plugin/skills/pumpkin/SKILL.md` is the authoritative setup skill. To install it
for a project:

```bash
mkdir -p .github/skills/pumpkin
cp plugin/skills/pumpkin/SKILL.md .github/skills/pumpkin/SKILL.md
```

Edit the source and recopy it; no plugin manifest or automatic installation is
provided. The skill guides provisioning and diagnostics, not ongoing polling.

## Development checks

Python 3.10+ can run the standard-library test suite without installing a package:

```bash
python3 -m unittest discover -s tests -t . -v
python3 firmware/plasma2350w/deploy.py bundle build/plasma-firmware
```

Tests cover exact arithmetic, rendering, demo timing, button debounce, power
limiting, RTC conversion, deployment and real local TLS verification failures.
Public DNS, NTP and GitHub TLS were also exercised from a desktop using a synthetic
invalid credential, not a live billing token. Physical UF2 heap/frame timing,
live-account mapping, current, thermals and soak operation remain deployment
checks. All flashes, white recharge and sparkle effects retain the configured
brightness/current caps.

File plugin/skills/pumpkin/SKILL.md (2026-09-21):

---
name: pumpkin
description: Configure and diagnose the standalone PumpkinPi Plasma 2350 W AI-credit candle without exposing credentials or spending credits.
---

# PumpkinPi setup and diagnostics

The board connects directly to GitHub over HTTPS. Never infer billing state from
Copilot token usage, premium-request quota, model activity or a demo animation.
Never ask the user to paste a token into chat. Never put it on a command line,
print `.env`, or collect a flash dump.

## Safe workflow

1. Establish the actual payer/account, named allowance or budget, exact unit,
   product/SKU/quantity mapping, and minimally privileged credential access.
   Fetch success alone does not establish a remaining balance.
2. Follow `firmware/plasma2350w/README.md`: copy the GitHub config and `.env.example`
   templates to ignored private files. The owner enters Wi-Fi credentials and a
   revocable GitHub token locally. Board flash is physically readable.
3. Install the serial upload tool from `firmware/plasma2350w/requirements.txt`.
   Upload only explicitly approved files with `deploy.py install --config ...
   --env ...`, then reset the board. No desktop service is needed afterward.
4. Diagnose the onboard status LED and secret-free startup/network error. Check
   outbound DNS/NTP/HTTPS, RTC, CA bundle and response bounds. Never weaken
   certificate checks or guess billing units to make an error disappear.
5. Explain that button A starts a latched animation demo, marked by blue status.
   It runs three full 63-second cycles, holds an orange/golden candle for 60
   minutes, then repeats one full cycle followed by another 60-minute hold.
   Startup also falls back to demo after 30 seconds without fresh valid data.
   Missing/invalid configuration or environment enters setup demo immediately
   with a secret-free error and no network provider. Blank templates are only
   for an explicitly approved unprovisioned board; never overwrite credentials.
   Inspect the error and `startup_demo_timeout_seconds`, then reset/power-cycle
   to retry normal mode. Full/demo sparkles do not prove remaining credits.
6. Point the owner to `docs/plasma-runtime.md` for accounting and diagnostics, and
   the firmware README for upload, token rotation and exact demo timings.
   `.github/copilot-instructions.md` contains Windows serial REPL commands and
   the physical-board smoke-test procedure.

Confirmed configured-budget zero ends in a dull flicker, not black. Recovery rises
to white over one second, then returns to the candle. Sparkles at unlimited credits
require an explicitly approved `source.unlimited: true` and null allowance.
Missing usage, failed authorization and paid overages never imply unlimited.
Credential changes and device uploads require explicit owner approval.

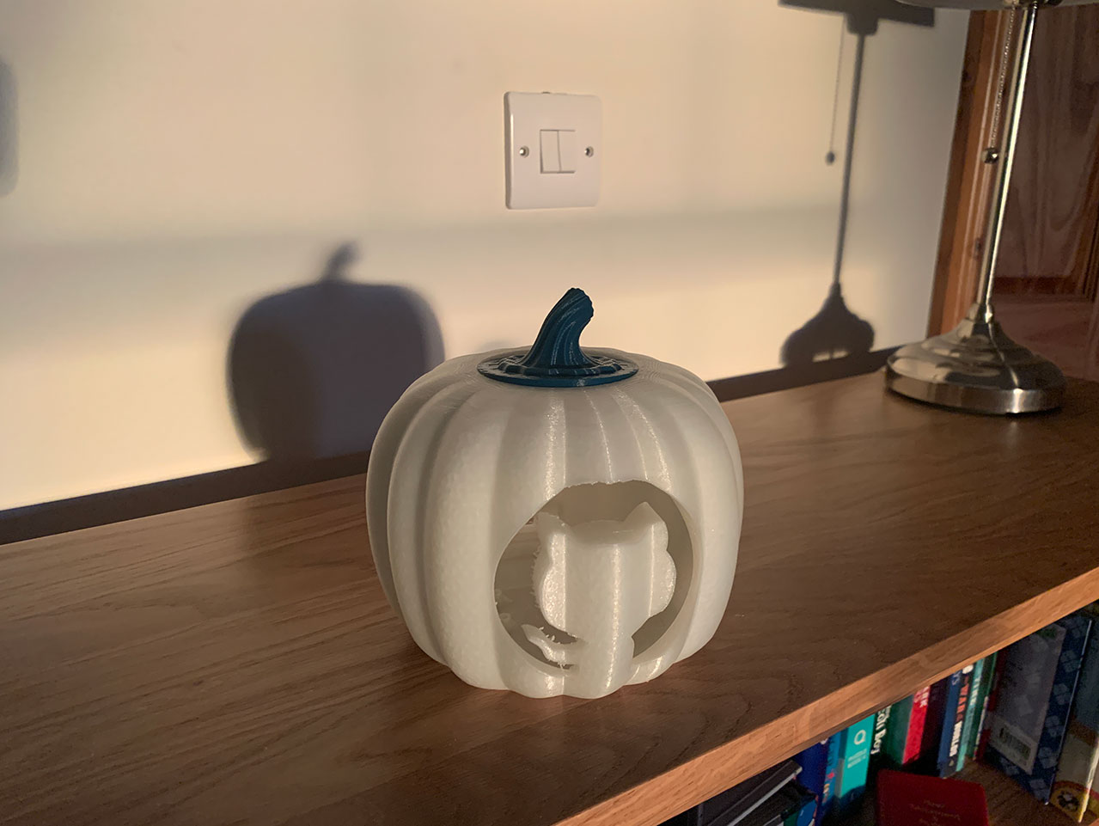
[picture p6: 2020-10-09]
images/pumpkin-shelf.jpg

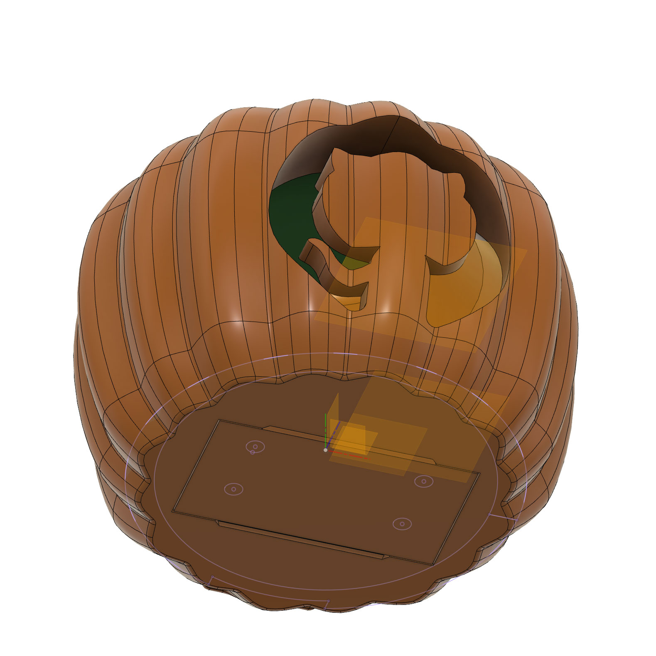
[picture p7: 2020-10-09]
images/pumpkinpi-render-bottom.jpg

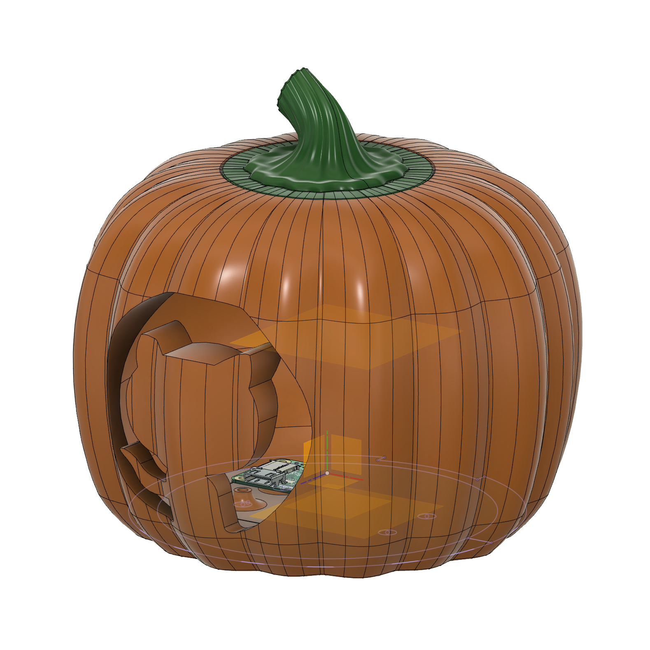
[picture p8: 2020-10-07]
images/pumpkinpi-render-top.png

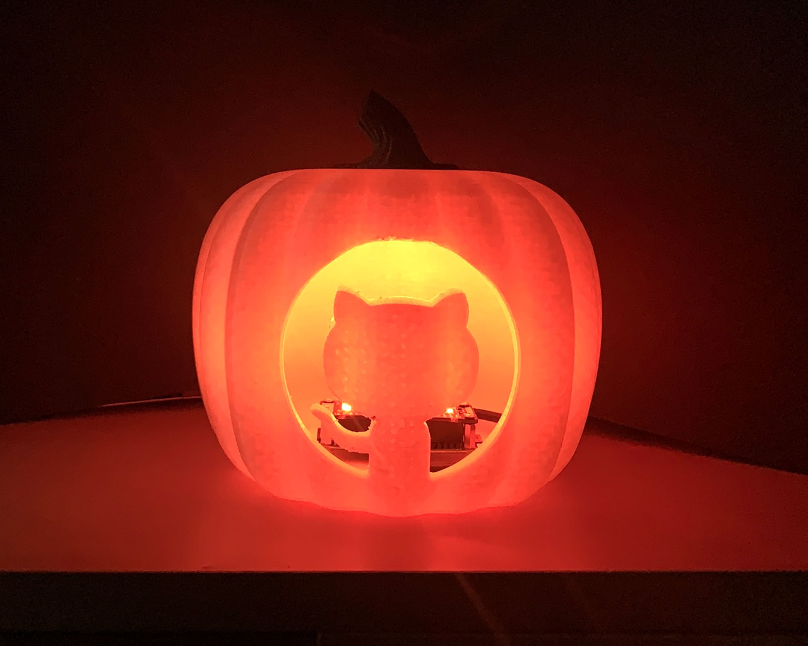
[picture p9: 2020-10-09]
images/pumpkin-orange.jpg

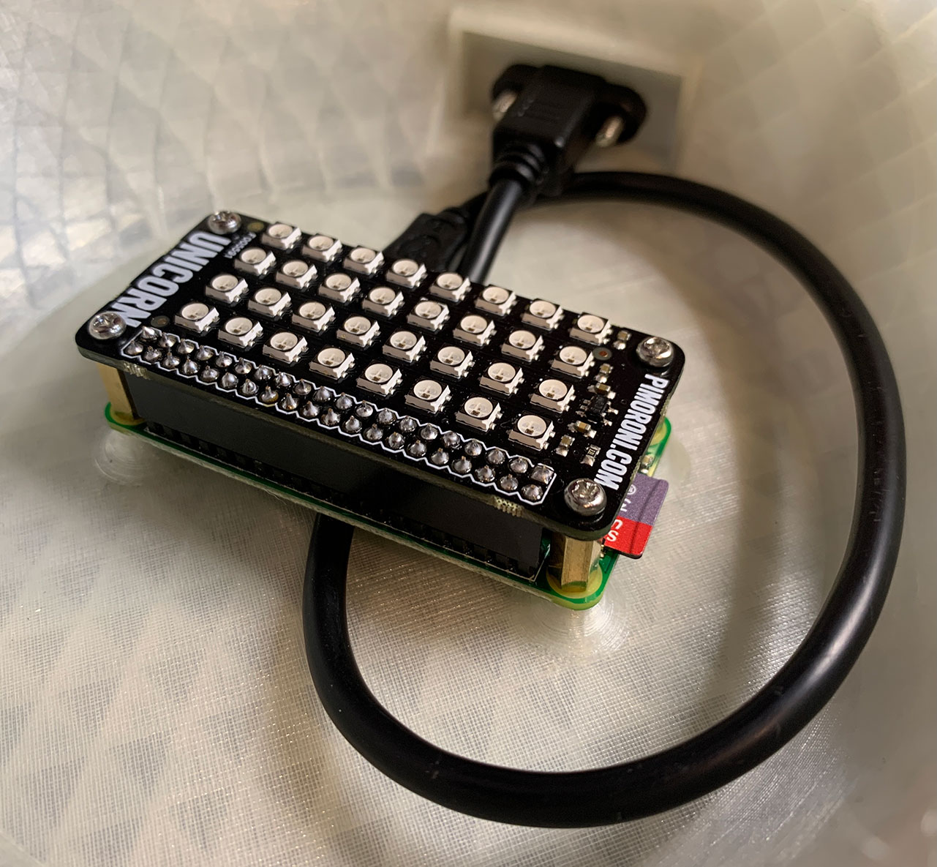
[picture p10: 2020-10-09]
images/pumpkin-guts.jpg

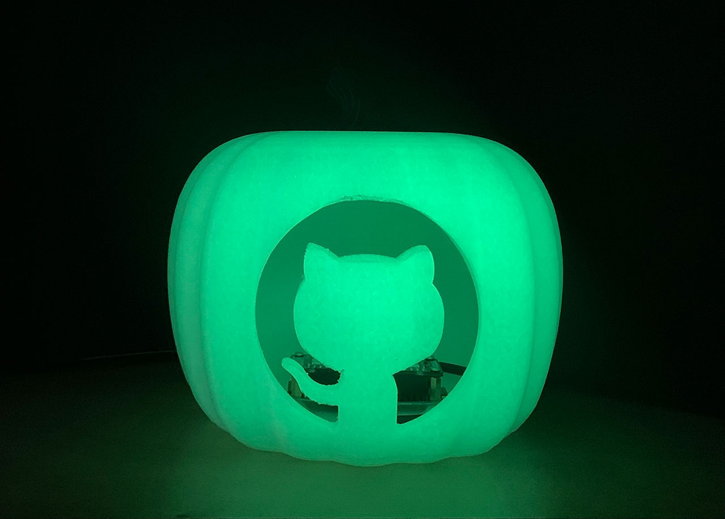
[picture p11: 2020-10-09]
images/pumpkin-green.jpg

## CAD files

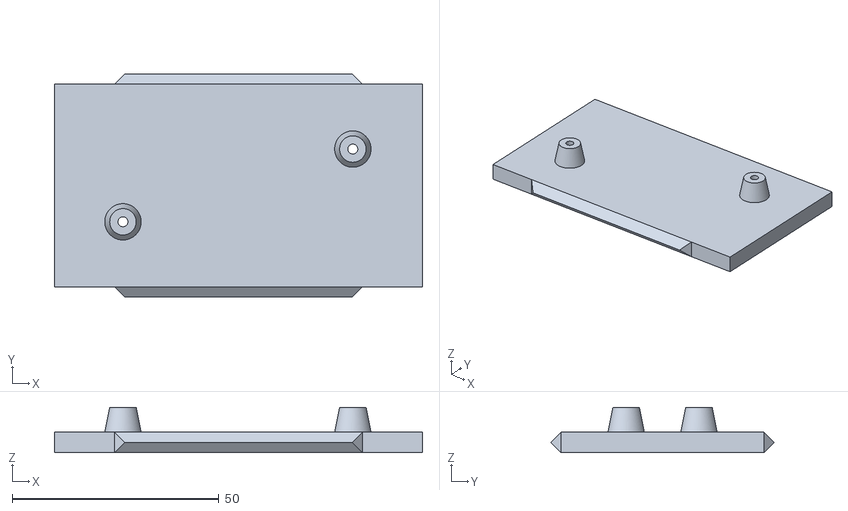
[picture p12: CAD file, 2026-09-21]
stl/plasma-2350-w/plasma2350-holder.stl
89.0 x 54.0 x 11.0

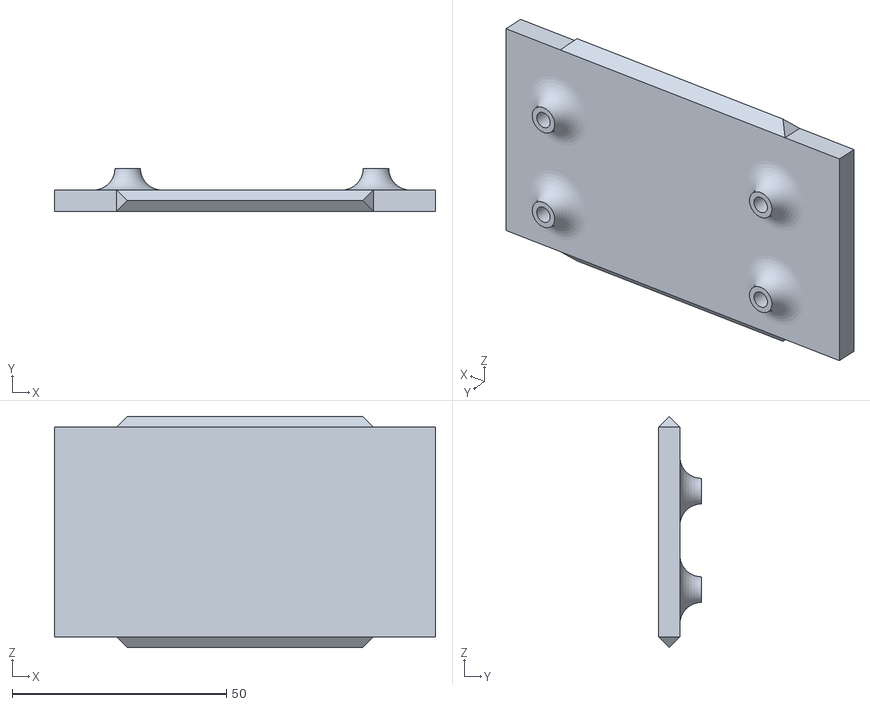
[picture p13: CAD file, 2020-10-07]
stl/pumpkin-pi-holder.stl
89.0 x 10.0 x 54.0

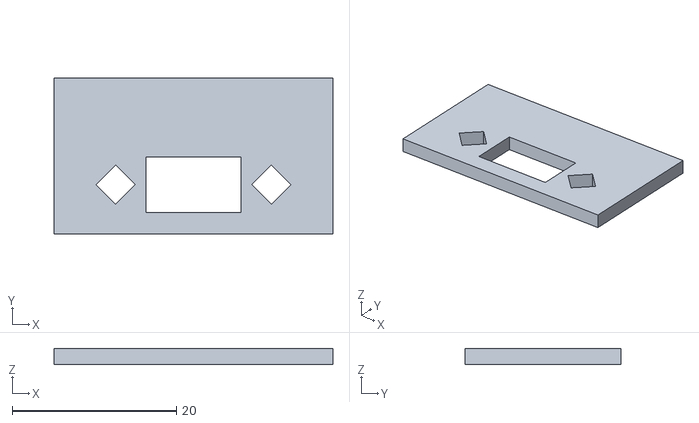
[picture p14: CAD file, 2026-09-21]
stl/plasma-2350-w/usb-c-fit-coupon.stl
34.0 x 19.0 x 2.00

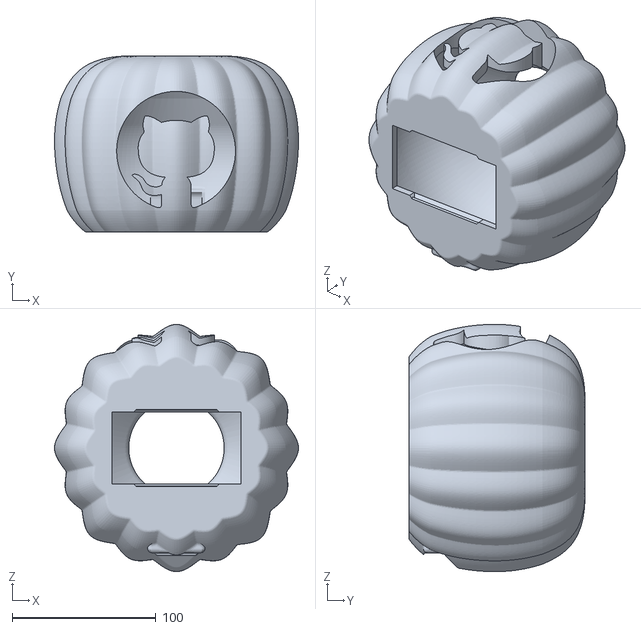
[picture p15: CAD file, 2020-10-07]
stl/pumpkin-body.stl
170.0 x 122.7 x 172.3

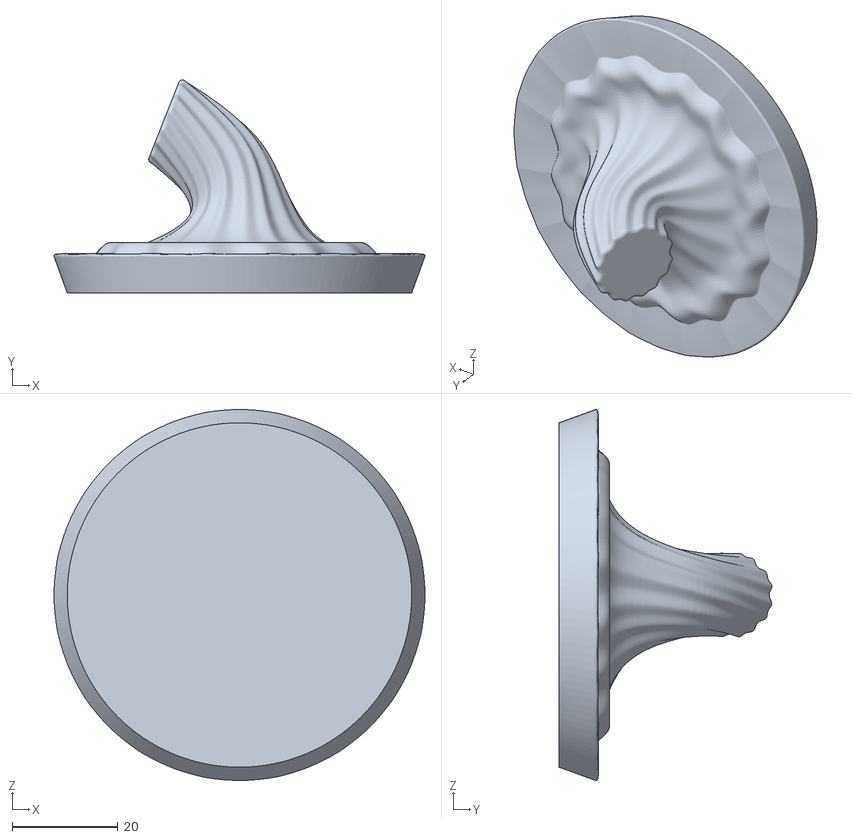
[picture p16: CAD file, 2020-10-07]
stl/pumpkin-plug.stl
70.0 x 40.2 x 70.0

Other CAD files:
stl/plasma-2350-w/pumpkin-body.stl

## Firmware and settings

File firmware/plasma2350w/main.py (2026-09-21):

"""PumpkinPi Plasma 2350 W entry point."""

import json
import math
import time

from pumpkinpi_core.accounting import AccountingReducer
from pumpkinpi_core.candle import CandleRenderer
from pumpkinpi_core.power import PowerLimiter
from pumpkinpi_core.runtime import DisplayController
from pumpkinpi_core.timebase import valid_unix_utc, unix_gmtime, port_epoch_offset
from pumpkinpi_core.billing import validate_source
from environment import load_environment
from hardware import PlasmaHardware
from providers.github import DirectGitHubClient
from scheduler import Scheduler


class Clock:
    _utc_anchor = None
    _ticks_anchor = None
    _last_ticks = None
    _elapsed_ms = 0

    @staticmethod
    def ticks_ms():
        function = getattr(time, "ticks_ms", None)
        if function:
            return function()
        monotonic = getattr(time, "monotonic", None)
        if monotonic:
            return int(monotonic() * 1000)
        return int(time.time() * 1000)

    @staticmethod
    def ticks_diff(left, right):
        function = getattr(time, "ticks_diff", None)
        return function(left, right) if function else left - right

    @staticmethod
    def ticks_add(value, delta):
        function = getattr(time, "ticks_add", None)
        return function(value, delta) if function else value + delta

    @staticmethod
    def utc():
        if Clock._utc_anchor is not None:
            current = Clock.ticks_ms()
            elapsed = Clock.ticks_diff(current, Clock._last_ticks)
            if elapsed >= 0:
                Clock._elapsed_ms += elapsed
                Clock._last_ticks = current
                return Clock._utc_anchor + Clock._elapsed_ms // 1000
        return None

    @staticmethod
    def sync_utc(epoch):
        if not valid_unix_utc(epoch):
            raise ValueError("remote UTC is out of range")
        Clock._utc_anchor = epoch
        Clock._ticks_anchor = Clock.ticks_ms()
        Clock._last_ticks = Clock._ticks_anchor
        Clock._elapsed_ms = 0


def load_config(path="config.json"):
    with open(path, "r") as handle:
        config = json.load(handle)
    if not isinstance(config, dict):
        raise ValueError("configuration must be an object")
    if config.get("provider", "github") != "github":
        raise ValueError("provider must be github")
    required = ("profile_id", "config_generation", "balance_basis",
                "budget_revision", "device_id")
    for name in required:
        if name not in config:
            raise ValueError("missing config field: " + name)
    text_fields = ["profile_id", "balance_basis", "budget_revision", "device_id"]
    for name in text_fields:
        if not isinstance(config[name], str) or not config[name] \
                or len(config[name]) > 128:
            raise ValueError("invalid config field: " + name)
    generation = config["config_generation"]
    if isinstance(generation, bool) or not isinstance(generation, int) \
            or not 0 <= generation <= 0xffffffff:
        raise ValueError("config_generation must be an unsigned 32-bit integer")
    validate_source(config.get("source"))
    interval = config.get("billing_poll_interval_seconds", 300)
    if type(interval) is not int or not 30 <= interval <= 86400:
        raise ValueError("billing_poll_interval_seconds must be 30..86400")
    for name, default in (("environment_file", ".env"),
                          ("ca_file", "certs/github-root.pem"),
                          ("time_floor_file", "direct-time.json"),
                          ("ntp_host", "pool.ntp.org")):
        value = config.get(name, default)
        if not isinstance(value, str) or not value or len(value) > 128 \
                or any(ord(char) < 32 for char in value):
            raise ValueError("invalid " + name)
    if config.get("color_order", "RGB") not in ("RGB", "RBG", "GRB", "GBR",
                                                "BRG", "BGR"):
        raise ValueError("unsupported color_order")
    for name, default, low, high in (
        ("max_brightness", 1.0, 0, 1),
        ("max_led_milliamps", 1500, 48, 100000),
        ("idle_ma_per_pixel", .5, 0, 100),
        ("channel_ma", 20, 0.001, 1000),
        ("stale_after_seconds", 900, 1, 86400),
        ("startup_demo_timeout_seconds", 30, 0, 300),
    ):
        value = config.get(name, default)
        if isinstance(value, bool) or not isinstance(value, (int, float)) \
                or not math.isfinite(value) or not low < value <= high:
            raise ValueError("invalid " + name)
    seed = config.get("flicker_seed", 2350)
    if isinstance(seed, bool) or not isinstance(seed, int) \
            or not 0 <= seed <= 0xffffffff:
        raise ValueError("invalid flicker_seed")
    if config.get("max_led_milliamps", 1500) < \
            96 * config.get("idle_ma_per_pixel", .5):
        raise ValueError("max_led_milliamps is below modeled idle current")
    if config.get("exhaustion_policy", "none") not in \
            ("none", "configured-budget"):
        raise ValueError("invalid exhaustion_policy")
    return config


def build_controller(config, provision):
    limiter = PowerLimiter(
        pixels=96,
        max_brightness=config.get("max_brightness", 1.0),
        max_milliamps=config.get("max_led_milliamps", 1500),
        idle_ma_per_pixel=config.get("idle_ma_per_pixel", 0.5),
        channel_ma=config.get("channel_ma", 20.0),
    )
    return DisplayController(
        AccountingReducer(provision, config.get("stale_after_seconds", 900)),
        CandleRenderer(96, config.get("flicker_seed", 2350)),
        limiter,
    )


def build(config, env=None):
    if env is None:
        env = load_environment(config.get("environment_file", ".env"))
    import network
    wlan = network.WLAN(network.STA_IF)
    provision = {
        "profile_id": config["profile_id"],
        "config_generation": config["config_generation"],
        "balance_basis": config["balance_basis"],
        "budget_revision": config["budget_revision"],
        "allow_confirmed_exhaustion":
            config.get("exhaustion_policy") == "configured-budget",
        "allow_unlimited": config["source"].get("unlimited", False),
    }
    controller = build_controller(config, provision)
    transport = DirectGitHubClient(
        config, env["GITHUB_TOKEN"], Clock(), set_board_utc, wlan,
        env["WIFI_SSID"], env["WIFI_PASSWORD"])
    return Scheduler(Clock(), PlasmaHardware(96, config.get("color_order", "RGB")),
                     transport, controller, startup_demo_timeout_seconds=
                     config.get("startup_demo_timeout_seconds", 30))


def build_setup_demo(reason, config=None):
    # Never use partially validated electrical settings or synthetic accounting.
    config = {} if config is None else config
    controller = build_controller(config, {})
    controller.reducer.record_error(reason)
    scheduler = Scheduler(
        Clock(), PlasmaHardware(96, config.get("color_order", "RGB")),
        None, controller)
    print("Setup required: " + reason + "; edit config.json and .env on the board")
    scheduler.start_demo("setup required", 0)
    return scheduler


def build_startup():
    try:
        config = load_config()
    except (OSError, ValueError):
        return build_setup_demo("config.json missing, unreadable or invalid")
    try:
        env = load_environment(config.get("environment_file", ".env"))
    except ValueError:
        return build_setup_demo(".env missing, unreadable or invalid", config)
    # Hardware, code and TLS time-floor failures must not become setup demos.
    return build(config, env)


def set_board_utc(epoch):
    from machine import RTC
    value = unix_gmtime(epoch, time)
    RTC().datetime((value[0], value[1], value[2], value[6],
                    value[3], value[4], value[5], 0))
    actual = int(time.time()) + port_epoch_offset(time)
    if abs(actual - epoch) > 5:
        raise ValueError("RTC did not accept UTC; TLS must not proceed")
    Clock.sync_utc(epoch)


def run():
    scheduler = None
    try:
        scheduler = build_startup()
        while True:
            scheduler.tick()
            sleeper = getattr(time, "sleep_ms", None)
            sleeper(2) if sleeper else time.sleep(0.002)
    finally:
        if scheduler is not None:
            try:
                scheduler.hardware.black()
            finally:
                close = getattr(getattr(scheduler, "transport", None), "close", None)
                if close is not None:
                    close()


if __name__ == "__main__":
    run()

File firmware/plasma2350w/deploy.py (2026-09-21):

"""Export or upload the complete MicroPython firmware bundle."""

import argparse
import shutil
import subprocess
from pathlib import Path

FILES = [
    "main.py", "hardware.py", "scheduler.py", "environment.py",
    "pumpkinpi_core/__init__.py", "pumpkinpi_core/accounting.py",
    "pumpkinpi_core/candle.py", "pumpkinpi_core/power.py",
    "pumpkinpi_core/runtime.py",
    "pumpkinpi_core/timebase.py",
    "pumpkinpi_core/billing.py",
    "pumpkinpi_core/demo.py",
    "providers/__init__.py",
    "providers/github.py", "providers/direct_network.py",
    "certs/github-root.pem",
]


def export_bundle(destination):
    source = Path(__file__).resolve().parent
    destination = Path(destination)
    for relative in FILES:
        target = destination / relative
        target.parent.mkdir(parents=True, exist_ok=True)
        shutil.copy2(source / relative, target)
    return list(FILES)


def deploy(destination):
    """Backward-compatible bundle export; this does not access a USB device."""
    return export_bundle(destination)


def mpremote_commands(device=None, config=None, executable="mpremote", env=None):
    prefix = [executable]
    if device:
        prefix += ["connect", device]
    commands = [prefix + ["exec",
        "import os\nfor p in ('pumpkinpi_core','providers','certs'):\n"
        " try: os.mkdir(p)\n"
        " except OSError:\n"
        "  if not (os.stat(p)[0] & 0x4000): raise"]]
    source = Path(__file__).resolve().parent
    for relative in FILES:
        commands.append(prefix + ["fs", "cp", str(source / relative),
                                  ":" + relative])
    if config is not None:
        commands.append(prefix + ["fs", "cp", str(Path(config).resolve()),
                                  ":config.json"])
    if env is not None:
        commands.append(prefix + ["fs", "cp", str(Path(env).resolve()), ":.env"])
    return commands


def install(device=None, config=None, executable="mpremote", runner=subprocess.run,
            env=None):
    for command in mpremote_commands(device, config, executable, env):
        runner(command, check=True)
    return list(FILES)


if __name__ == "__main__":
    parser = argparse.ArgumentParser()
    commands = parser.add_subparsers(dest="command", required=True)
    bundle = commands.add_parser("bundle", help="export files to a local folder")
    bundle.add_argument("destination")
    upload = commands.add_parser(
        "install", help="upload to a running MicroPython board with mpremote")
    upload.add_argument("--device", help="serial device, such as /dev/cu.usbmodem...")
    upload.add_argument("--config", help="private board config.json to upload")
    upload.add_argument("--env", help="explicitly upload private Wi-Fi/GitHub .env")
    upload.add_argument("--mpremote", default="mpremote")
    args = parser.parse_args()
    if args.command == "bundle":
        copied = export_bundle(args.destination)
        print("Exported %d firmware files; no device was accessed." % len(copied))
    else:
        copied = install(args.device, args.config, args.mpremote, env=args.env)
        print("Uploaded %d firmware files to MicroPython storage." % len(copied))

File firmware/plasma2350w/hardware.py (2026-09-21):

"""Plasma 2350 W hardware adapter. This is the only module importing board APIs."""


class PlasmaHardware:
    def __init__(self, pixels=96, color_order="RGB", strip=None, status_led=None,
                 button_a=None):
        self.pixels = pixels
        real_hardware = strip is None
        if strip is None:
            import plasma
            order = getattr(plasma, "COLOR_ORDER_" + color_order)
            strip = plasma.WS2812(pixels, color_order=order)
        self.strip = strip
        self.status_led = status_led
        if real_hardware and self.status_led is None:
            self.status_led = self._make_status_led()
        if real_hardware and button_a is None:
            from machine import Pin
            button_a = Pin("SW_A", Pin.IN, Pin.PULL_UP)
        self.button_a = button_a
        self.black()
        self.strip.start(60)

    def _make_status_led(self):
        from pimoroni import RGBLED
        return RGBLED("LED_R", "LED_G", "LED_B")

    def write(self, frame):
        if len(frame) != self.pixels:
            raise ValueError("frame length mismatch")
        for index, rgb in enumerate(frame):
            self.strip.set_rgb(index, rgb[0], rgb[1], rgb[2])

    def black(self):
        for index in range(self.pixels):
            self.strip.set_rgb(index, 0, 0, 0)

    def button_a_pressed(self):
        return self.button_a is not None and self.button_a.value() == 0

    def status(self, state):
        colors = {
            "ok": (0, 40, 0),
            "estimated": (50, 20, 0),
            "unknown": (40, 15, 0),
            "stale": (35, 0, 20),
            "error": (50, 0, 0),
            "depleted": (0, 0, 0),
            "demo": (0, 0, 40),
        }
        if self.status_led is not None:
            self.status_led.set_rgb(*colors.get(state, colors["error"]))

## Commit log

2018-10-24 (doc) Fix typo
    Based on a search of Urban Dictionary, it would appear that spelling it as `unkown` is a valid usage:
    https://www.urbandictionary.com/define.php?term=unkown
    But still, once seen, it couldn't be unseen, and I had to change it 😋
2020-10-07 Add STL models and renders
    [pumpkin-body.stl, pumpkin-pi-holder.stl, pumpkin-plug.stl]
2020-10-07 Add link to STL files
2026-09-19 Add standalone Plasma 2350 W credit candle and enclosure
    Implement direct verified GitHub HTTPS, board-local credential provisioning, credit-driven candle effects and button-A demo mode. Add the Plasma holder, USB-C body revision, uniform Octocat relief an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
    [plasma2350-holder.stl, pumpkin-body.stl, usb-c-fit-coupon.stl]
2026-09-21 Support board setup demo and recurring animation playback
    Match attached RGB strip brightness and channel order, preserve current-limited recharge, add real-board verification, and document serial deployment and testing.
